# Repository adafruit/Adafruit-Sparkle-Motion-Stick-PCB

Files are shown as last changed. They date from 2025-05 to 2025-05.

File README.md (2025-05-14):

## Adafruit Sparkle Motion Stick - WLED-friendly USB Stick PCB

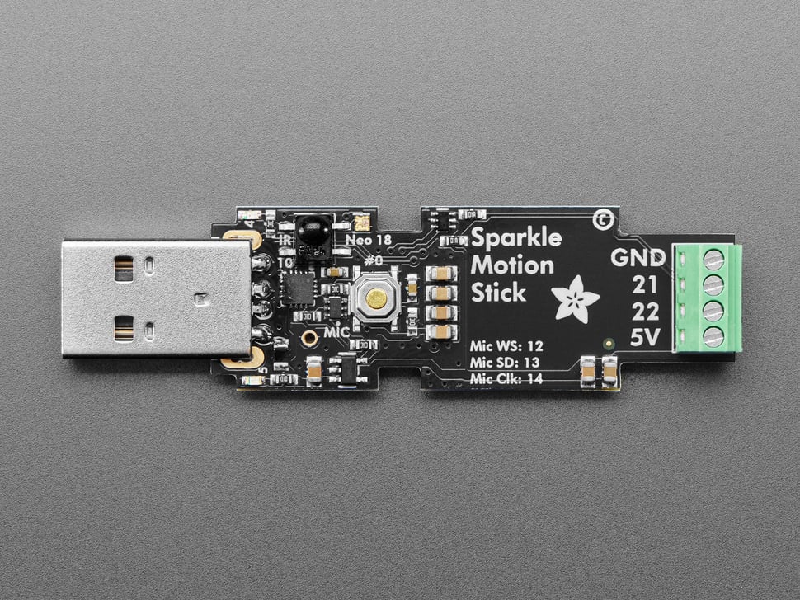
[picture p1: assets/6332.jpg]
<a href="http://www.adafruit.com/products/6332"><br/>
Click here to purchase one from the Adafruit shop</a>

PCB files for the Adafruit Sparkle Motion Stick - WLED-friendly USB Stick. 

Format is EagleCAD schematic and board layout
* https://www.adafruit.com/product/6332

### Description

The Adafruit Sparkle Motion Stick is part of our series of "Sparkle Motion" boards, which are our attempt to make the best small WLED-friendly smart LED driving board in the whole world. Our resident mermaid, firepixie makes a lot of projects with WLED, and she loves it! So, how can we make something powerful enough to drive advanced LED projects that need a compact design?

The USB Stick version of the Sparkle Motion is a simpler version of our full-featured Sparkle Motion. It even fits into a low cost off-the-shelf case for protection. Please note the case is not included with this product, so don't forget to pick one up if you want it in a case!

* Power via USB Type A for up to 5V 2A input - you can use off-the-shelf USB battery packs for portable operation.
* 2 Amp resetting fuse to protect from over-current drive
* ESP32 mini module with built-in antenna port - the classic ESP32 has the best WLED support, even if we'd prefer the 'S2 or 'S3. Comes with 4 MB of flash, dual-core 240MHz Tensilica, WiFi, Bluetooth LE, and Bluetooth Classic support.
* USB-serial converter with auto-reset
* Two output signals plus 5V power and ground - both signal outputs are level shifted to 5V.
* Built-in I2S microphone for audio-reactive projects
* Built-in Infrared receiver on GPIO 10 for easy remote control integration
* User button on GPIO 0 which you can press even when its in the snap-on case
* Red built-in LED on pin 4
* Small built-in NeoPixel on pin 18
* Screw terminal blocks for no-solder connectivity

Compared to our larger Sparkle Motion board, this only supports 5V and doesn't have a reset button, there are fewer outputs, and no breakout pads of I2C/GPIO connections for external accessories.
Compared to our Sparkle Motion Mini, this has a USB A port so it's 2A max power. It does have IR and built-in terminal blocks but does not have GPIO breakout pads.

While we recommend it for use with WLED, it will also work just fine as a compact ESP32 board for use with Arduino, ESP-IDF, MicroPython, CircuitPython, or any other ESP32-supported codebase. 

### License

Adafruit invests time and resources providing this open source design, please support Adafruit and open-source hardware by purchasing products from [Adafruit](https://www.adafruit.com)!

Designed by Limor Fried/Ladyada for Adafruit Industries.

Creative Commons Attribution/Share-Alike, all text above must be included in any redistribution. 
See license.txt for additional details.

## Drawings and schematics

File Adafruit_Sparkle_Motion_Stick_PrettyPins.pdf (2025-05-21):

# Adafruit Sparkle Motion Stick

# https://www.adafruit.com/product/6332

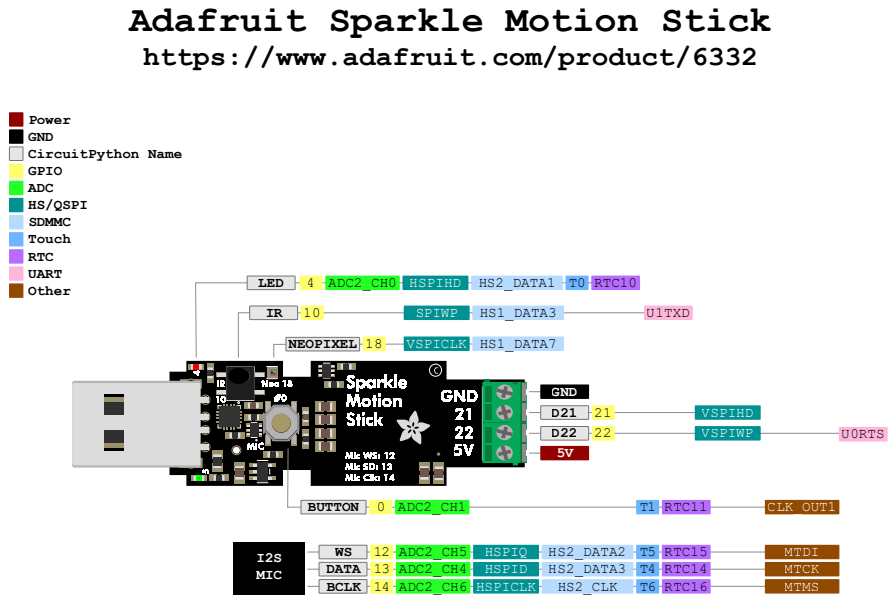
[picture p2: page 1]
VSPIWP; U0RTS; VSPIHD; GND; SPIWP HS1_DATA3; U1TXD; NEOPIXEL 18 VSPICLK HS1_DATA7; LED 4 ADC2_CH0 HSPIHD HS2_DATA1 T0 RTC10; BUTTON 0 ADC2_CH1; T1 RTC11; CLK_OUT1; WS 12 ADC2_CH5 HSPIQ HS2_DATA2 T5 RTC15; MTDI; DATA 13 ADC2_CH4 HSPID HS2_DATA3 T4 RTC14; MTCK; BCLK 14 ADC2_CH6 HSPICLK HS2_CLK T6 RTC16; MTMS; I2S MIC; Power GND CircuitPython Name GPIO ADC HS/QSPI SDMMC Touch RTC UART Other

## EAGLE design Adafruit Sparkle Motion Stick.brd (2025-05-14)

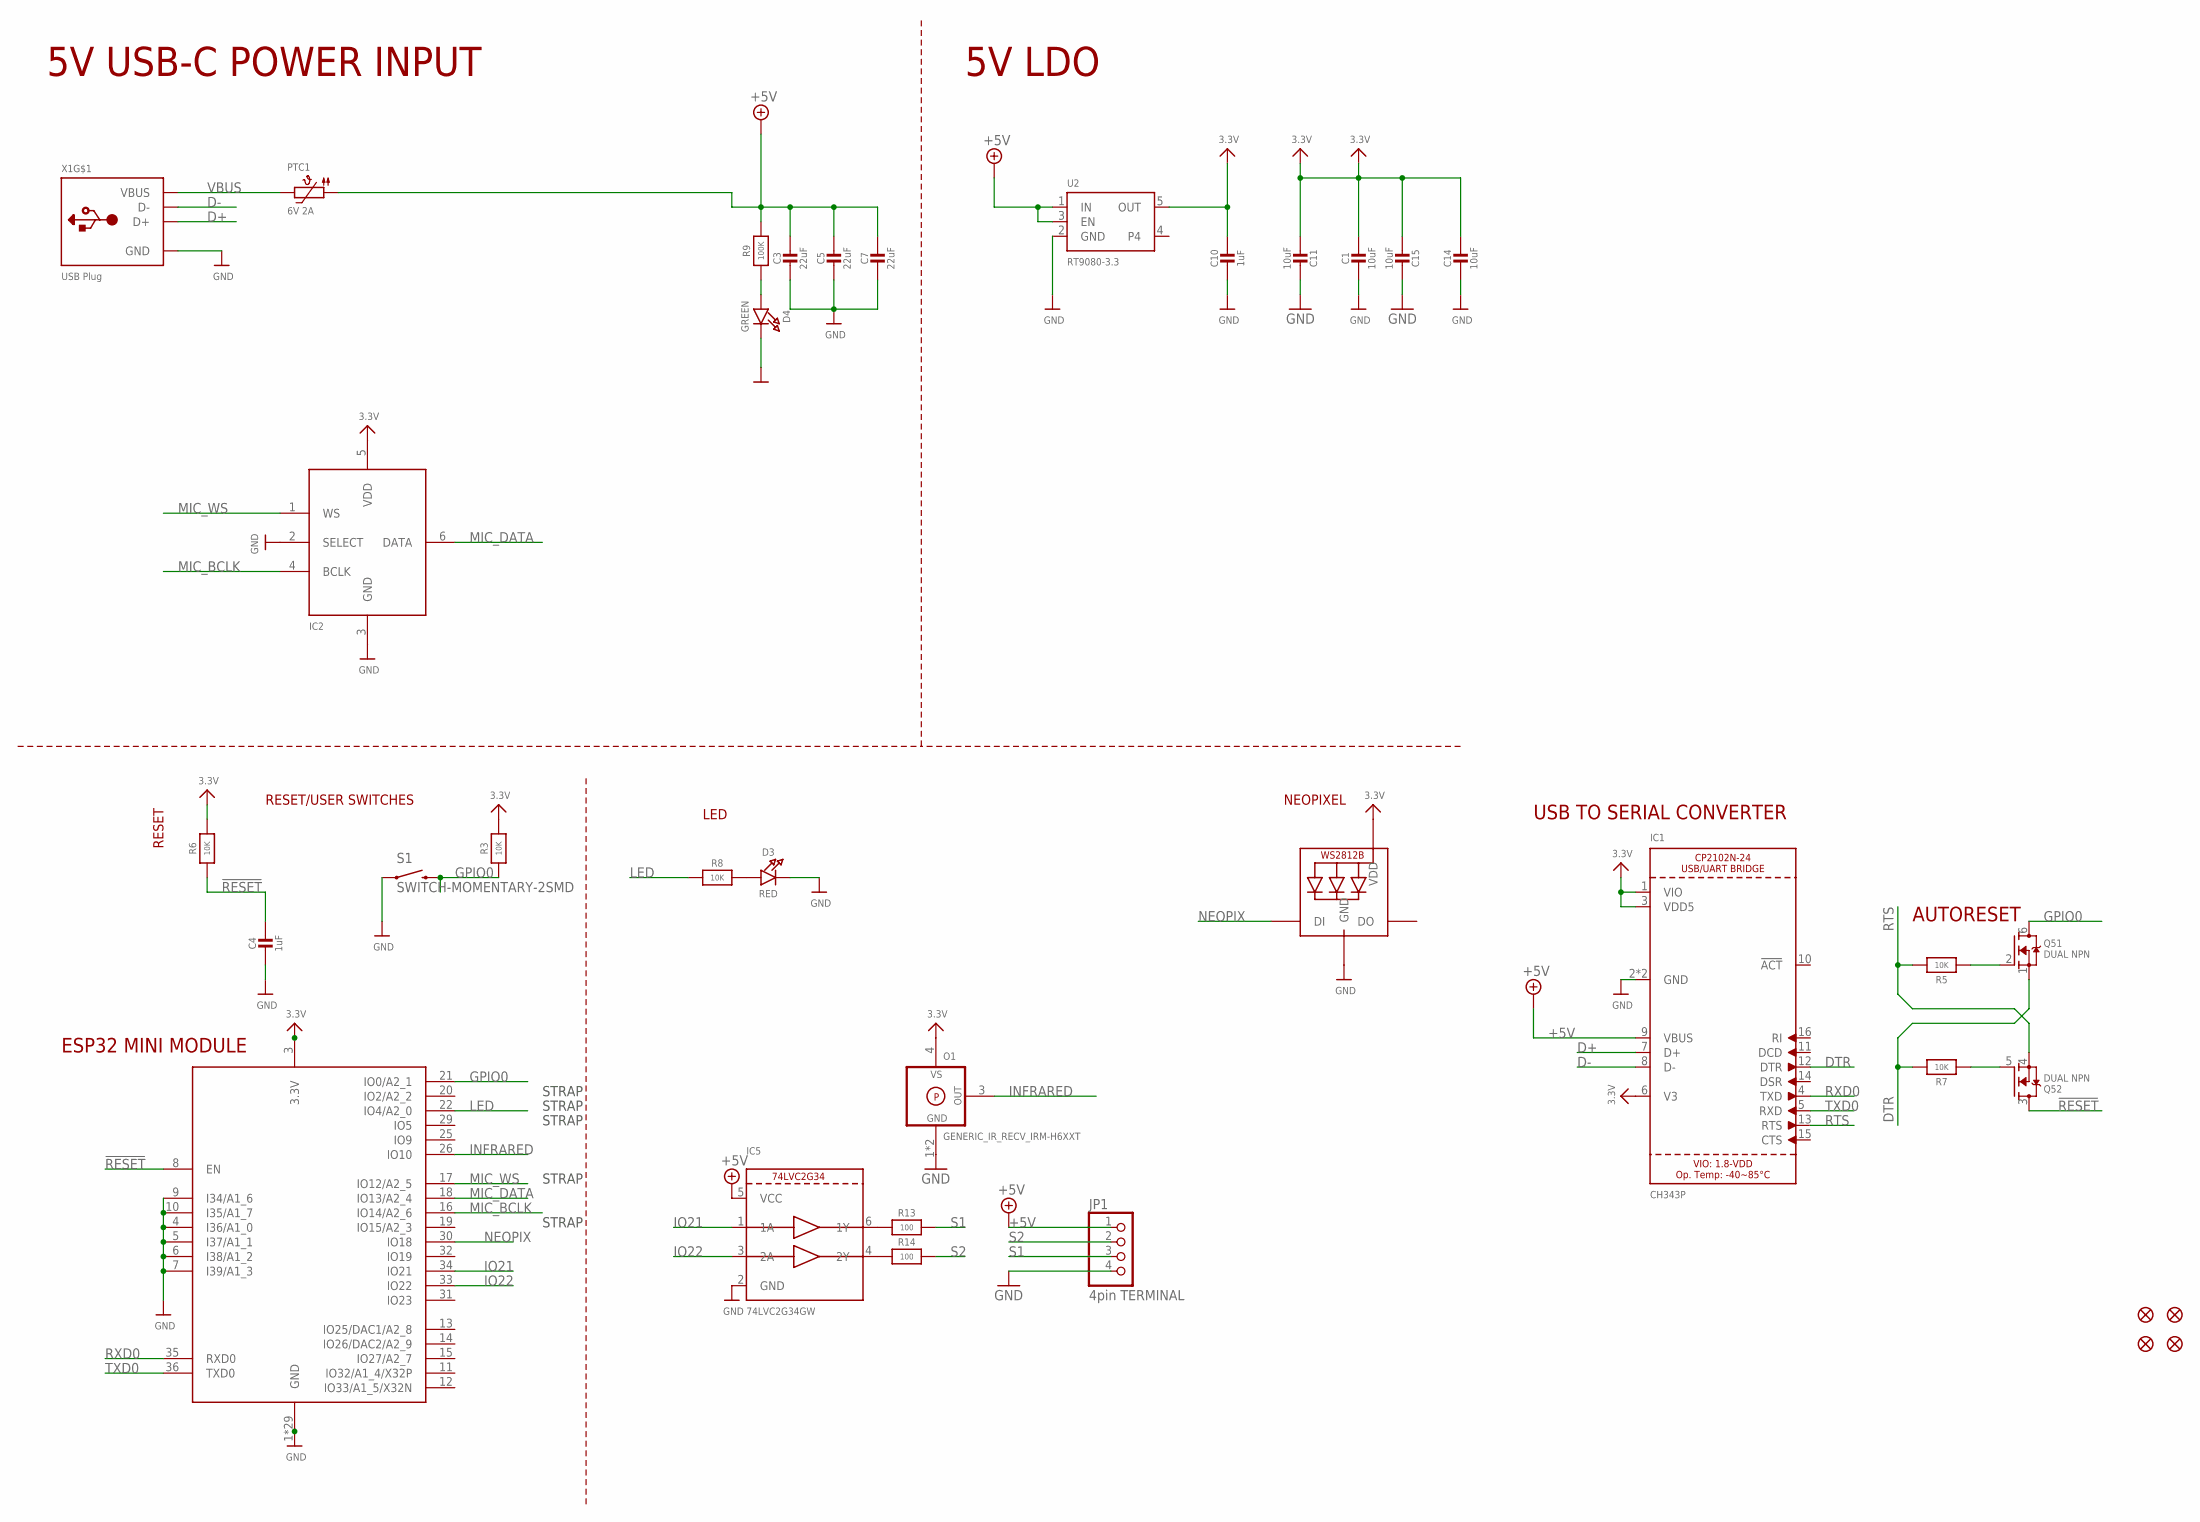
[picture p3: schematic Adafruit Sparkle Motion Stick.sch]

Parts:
C1, C11, C14, C15: 10uF; 0805-NO
C3, C5, C7: 22uF; 0805-NO
C4, C10: 1uF; 0603-NO
D3: RED; CHIPLED_0603_NOOUTLINE
D4: GREEN; CHIPLED_0603_NOOUTLINE
IC1: CH343P; QFN16_3MM
IC2: ICS-43434; SPH0645LM4H
IC5: 74LVC2G34GW; SC70-6L
JP1: 4pin TERMINAL; 1X04_2.54MMTERMINAL
LED1: WS2812B_SK6805_1515; SK6805_1515
O1: GENERIC_IR_RECV_IRM-H6XXT; IRM-H6XXT
PTC1: 6V 2A; 0805-NO
Q5: DUAL NPN; SOT363; JLC_ROTATION 90
R3, R5, R6, R7, R8: 10K; 0603-NO
R9: 100K; 0603-NO
R13, R14: 100; 0603-NO
S1: SWITCH-MOMENTARY-2SMD; TACTILE_SWITCH_SMD
U2: RT9080-3.3; SOT23-5; JLC_ROTATION 0
U$23, U$25, U$34, U$35: FIDUCIAL_0.5MM
X1: USB Plug; USB_A-UGO4DD
X4: ESP32-MINI-1

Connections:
3.3V: C1.1, C10.1, C11.1, C14.1, C15.1, IC1.1 (VIO), IC1.3 (VDD5), IC1.6 (V3), IC2.5 (VDD), LED1.2 (VDD), O1.4 (VS), R3.2, R6.2, U2.5 (OUT), X4.3 (3.3V)
!RESET: C4.1, Q5.3 (D), R6.1, X4.8 (EN)
+5V: C3.1, C5.1, C7.1, IC1.9 (VBUS), IC5.5 (VCC), JP1.1, PTC1.1, R9.2, U2.1 (IN), U2.3 (EN)
D+: IC1.7 (D+), X1.D+
D-: IC1.8 (D-), X1.D-
DTR: IC1.12 (DTR), Q5.1 (S), R7.2
GND: C1.2, C3.2, C4.2, C5.2, C7.2, C10.2, C11.2, C14.2, C15.2, D3.C, D4.C, IC1.2 (GND), IC1.THERMAL (GND), IC2.2 (SELECT), IC2.3 (GND), IC5.2 (GND), JP1.4, LED1.4 (GND), O1.1 (GND), O1.2 (GND), S1.1, U2.2 (GND), X1.GND, X4.1 (GND), X4.2 (GND), X4.4 (I36/A1_0), X4.5 (I37/A1_1), X4.6 (I38/A1_2), X4.7 (I39/A1_3), X4.9 (I34/A1_6), X4.10 (I35/A1_7), X4.27 (GND), X4.38 (GND), X4.39 (GND), X4.40 (GND), X4.41 (GND), X4.42 (GND), X4.43 (GND), X4.44 (GND), X4.45 (GND), X4.46 (GND), X4.47 (GND), X4.48 (GND), X4.49 (GND), X4.50 (GND), X4.51 (GND), X4.52 (GND), X4.53 (GND), X4.54 (GND), X4.55 (GND), X4.56 (GND), X4.57 (GND), X4.58 (GND), X4.59 (GND), X4.60 (GND), X4.61 (GND), X4.62 (GND), X4.63 (GND)
GPIO0: Q5.6 (D), R3.1, S1.3 (2), X4.21 (IO0/A2_1)
INFRARED: O1.3 (OUT), X4.26 (IO10)
IO21: IC5.1 (1A), X4.34 (IO21)
IO22: IC5.3 (2A), X4.33 (IO22)
LED: R8.1, X4.22 (IO4/A2_0)
MIC_BCLK: IC2.4 (BCLK), X4.16 (IO14/A2_6)
MIC_DATA: IC2.6 (DATA), X4.18 (IO13/A2_4)
MIC_WS: IC2.1 (WS), X4.17 (IO12/A2_5)
unnamed: D3.A, R8.2
unnamed: D4.A, R9.1
unnamed: Q5.5 (G), R7.1
unnamed: Q5.2 (G), R5.1
unnamed: IC5.6 (1Y), R13.1
unnamed: IC5.4 (2Y), R14.1
NEOPIX: LED1.1 (DI), X4.30 (IO18)
RTS: IC1.13 (RTS), Q5.4 (S), R5.2
RXD0: IC1.4 (TXD), X4.35 (RXD0)
S1: JP1.3, R13.2
S2: JP1.2, R14.2
TXD0: IC1.5 (RXD), X4.36 (TXD0)
VBUS: PTC1.2, X1.VBUS

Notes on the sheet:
5V USB-C POWER INPUT
RESET
LED
NEOPIXEL
ESP32 MINI MODULE
RESET/USER SWITCHES
AUTORESET
USB TO SERIAL CONVERTER
5V LDO
STRAP

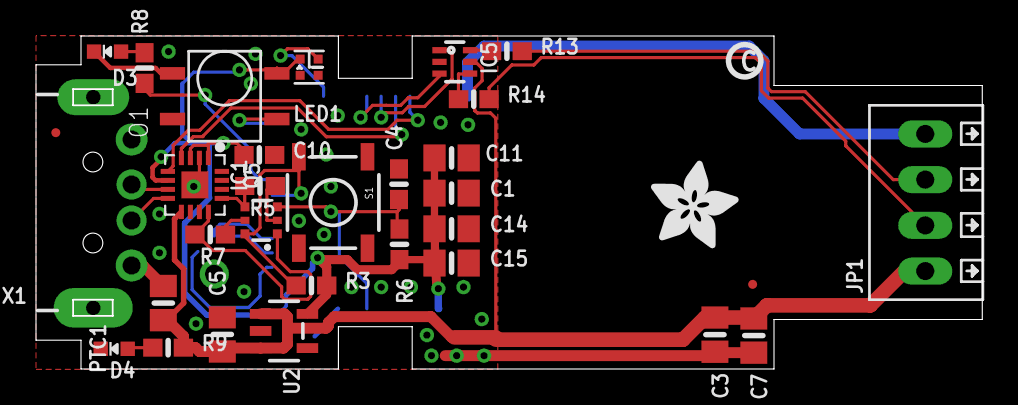
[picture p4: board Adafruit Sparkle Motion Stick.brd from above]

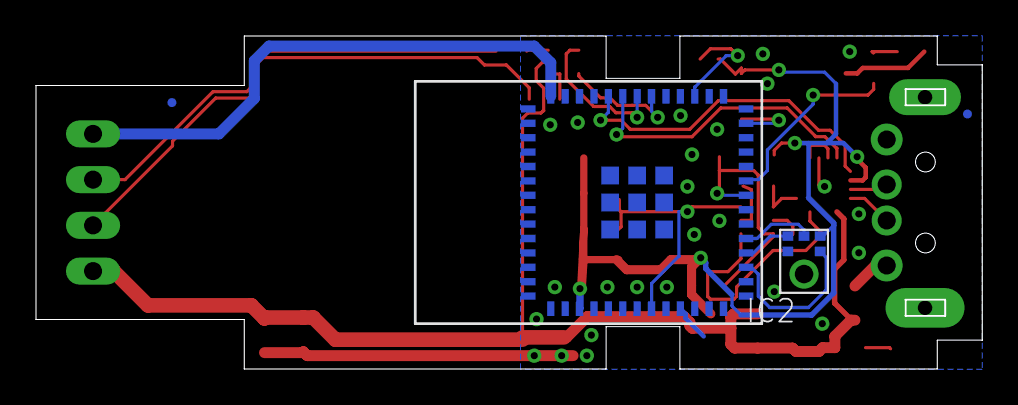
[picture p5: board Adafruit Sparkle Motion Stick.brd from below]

Board: 2 copper layers, 52.6 x 18.5 mm, 59 parts (11 on the bottom side), 28 nets.

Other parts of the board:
E$1: ADAFRUIT_5MM
PLABEL0: PLABEL0
PLABEL1: PLABEL1
PLABEL2: PLABEL2
PLABEL3: PLABEL3
PLABEL4: PLABEL4
PLABEL5: PLABEL5
PLABEL6: PLABEL6
PLABEL7: PLABEL7
PLABEL8: PLABEL8
PLABEL9: PLABEL9
PLABEL10: PLABEL10
PLABEL11: PLABEL11
PLABEL12: PLABEL12
PLABEL13: PLABEL13
PLABEL14: PLABEL14
PLABEL15: PLABEL15
PLABEL16: PLABEL16
PLABEL17: PLABEL17
PLABEL18: PLABEL18
PLABEL19: PLABEL19
PLABEL20: PLABEL20
PLABEL21: PLABEL21
U$10: PCBFEAT-REV-040

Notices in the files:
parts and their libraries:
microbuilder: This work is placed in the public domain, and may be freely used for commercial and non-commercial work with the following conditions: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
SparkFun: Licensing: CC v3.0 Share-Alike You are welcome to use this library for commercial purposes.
